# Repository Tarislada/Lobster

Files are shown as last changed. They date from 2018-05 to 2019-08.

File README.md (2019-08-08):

# Lobster

Lobster Bot Project

folked from Sunwhi Kimm's project

revised by Knowblesse

# Folders
## Apparatus
- 3D CAD data

## ArduinoCode
- Controller.ino
- Lobster.ino
- Sucrose Pump.ino

## MatlabCode
- Behavior & Spike analysis codes

## PythonCode
- Experimental Machine learning codes

## Schematic
- Schematics for Custom Arduino Shield

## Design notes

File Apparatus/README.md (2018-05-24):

# Lobster Unit Code

Lobster Bot 데이터 분석 코드

# Files
## functions
[**BehavDataParser**](#behavdataparser) : TDT Open Bridge 에서 추출한 행동 데이터 csv 파일을 불러온다.

[**createGaussianHitmap**](#creategaussianhitmap) : XY data로부터 hitmap을 그려냅니다.

[**drawmap**](#drawmap) : createGaussianHitmap 데이터를 그려주는 함수. (createGaussianHitmap 함수 내에서 dodraw를 true로 설정하면 필요 없음.)

[**firedLocationParser**](#firedlocationparser) : spike time 데이터가 있는 txt 파일을 읽어서 위치와 연결해준다.

[**getHeadDegree**](#getheaddegree) : 이전좌표와 이후 좌표를 기반으로 움직인 방향의 각도를 구합니다. (X+ 축이 0도, Y+축이 90도 입니다.)

[**locationParser**](#locationparser) : XYXY csv 파일을 읽어서 위치 값들을 뽑아 출력한다.(recoverLocData 포함)

[**recoverLocData**](#recoverlocdata) : tracking loss로 인한 데이터 손실 부분을 주변 데이터를 토대로 추측해서 재구성한다.

## Scripts
**AnalyticValueExtractor** : BehavDataParser를 돌린 후 돌리면 각 trial 별 Avoid(A) / Escape(E) / 1 min timeout(M) / Give up(G) / No Lick(N) 값을 출력한다.

### BehavDataParser
- input
	- **targetdir : string(path) :** csv 파일들이 있는 경로
- output
	- **ParsedData : {1,4} cell :** {[TRON Time, TROF Time], [[IRON, IROF]], [[LICK,LOFF]], [[ATTK, ATOF]]}
	- **Trials : [n, 2] array :** [TRON Time, TROF Time]
	- **IRs : [n, 2] array :** [IRON, IROF]
	- **Licks : [n,2] array :** [LICK,LOFF]
	- **Attacks : [n,2] array :** [ATTK, ATOF]

### createGaussianHitmap
- input
	- **xydata : [n, 2] array :** [xdata, ydata]
	- **distribution : double :** gaussian 분포를 만들기 위한 sigma 값.
	- **stride : int :** 처리 속도 향상을 위해서 넣은 숫자만큼 데이터를 건너뛰어 읽음. 1로 설정시 모든 데이터를 사용.
	- **axis_limit : [1, 4] array :** [xmin, xmax, ymin, ymax] hitmap 데이터의 x축의 범위, y축의 범위를 설정해줌.
	- **dodraw : boolean :** true로 설정시 hitmap 그래프를 그림. false로 설정시 나중에 따로 그려주어야 함.
- output
	- **map : [n, n] array :** hitmap data. surf 함수를 사용해서 그릴것.

### drawmap
- input
	- **map : [n, n] array :** hitmap data. createGaussianHitmap 함수에서 출력됨.
	- **axis_limit : [1, 4] array :** [xmin, xmax, ymin, ymax] hitmap 데이터의 x축의 범위, y축의 범위를 설정해줌.
	- **c_axis_limit : [1, 2] array :** colorbar를 그리기 위한 한계값. 
- output
	- **map : [n, n] array :** hitmap data. surf 함수를 사용해서 그릴것.

### firedLocationParser
- input
	- **result : [n, 6] array :** [시간, Red X, Red Y, Green X, Green Y, Head Direction] locationParser가 뱉어내는 result 파일. (실제로는 첫 Col 만 사용)
- output
	- **firedIndices : [n, 1] array :** locationParser의 result 파일을 기준으로 unit이 fire한 시간과 가장 가까운 indices

### getHeadDegree
- input
	- **x1 : double :** t 시간의 x좌표 
	- **y1 : double :** t 시간의 y좌표
	- **x2 : double :** t+1 시간의 x좌표
	- **y2 : double :** t+1 시간의 y좌표
- output
	- **head_degree : double :** 각도.

### locationParser
- input
	- **dodraw : boolean :** 결과값을 그래프로 그릴 지 말지를 결정한다.
- output
	- **result : [n, 6] array :** [시간, Red X, Red Y, Green X, Green Y, Head Direction] 
- warning
	- Col 2-5의 데이터는 open bridge 설정에 따라 Red와 Green이 바뀔 수 있으므로 주의할 것.

### recoverLocData
- input
	- **originalLocData : {2, 2} cell :** { Red X , Green X; Red Y, Green Y}
	- **X_RANGE : [1,2] array :** 정상적인 X 값의 범위. [xmin, xmax]
	- **Y_RANGE : [1,2] array :** 정상적인 Y 값의 범위. [ymin, ymax]
- output
	- **recoveredLocData : {2, 2} cell :** { Red X , Green X; Red Y, Green Y}
- warning
	- open bridge 설정에 따라서 정상적인 X, Y의 범위를 나타내는 X_Range, Y_Range 값을 바꿔줘야할 경우가 있음.

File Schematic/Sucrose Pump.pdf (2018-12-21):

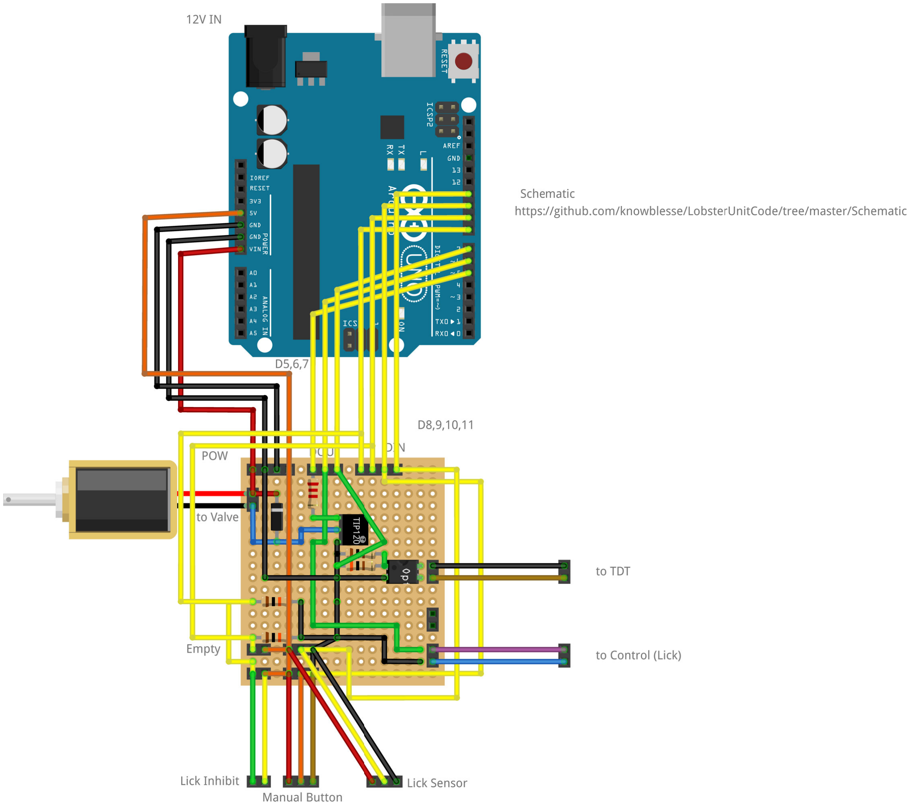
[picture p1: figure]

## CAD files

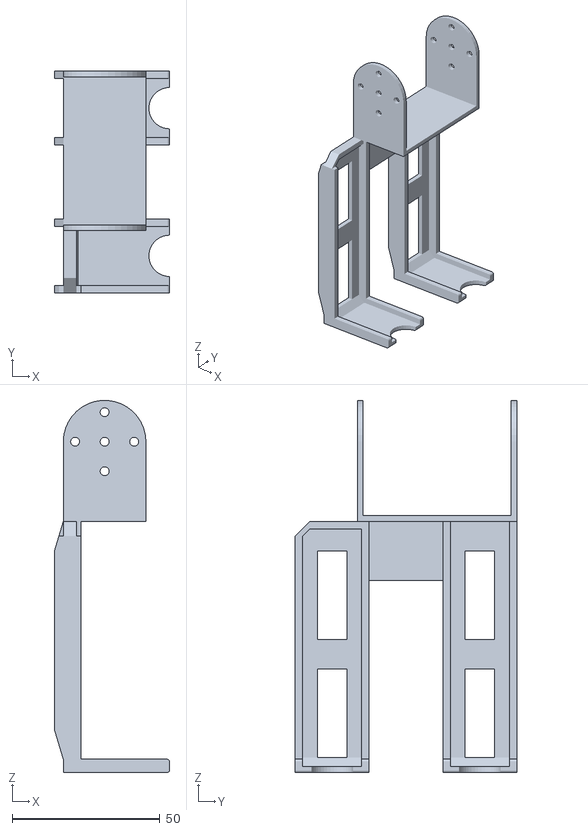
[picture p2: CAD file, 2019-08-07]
Apparatus/Box/servo_bracket_claw_left_v3-.STL
39.0 x 75.0 x 126.0

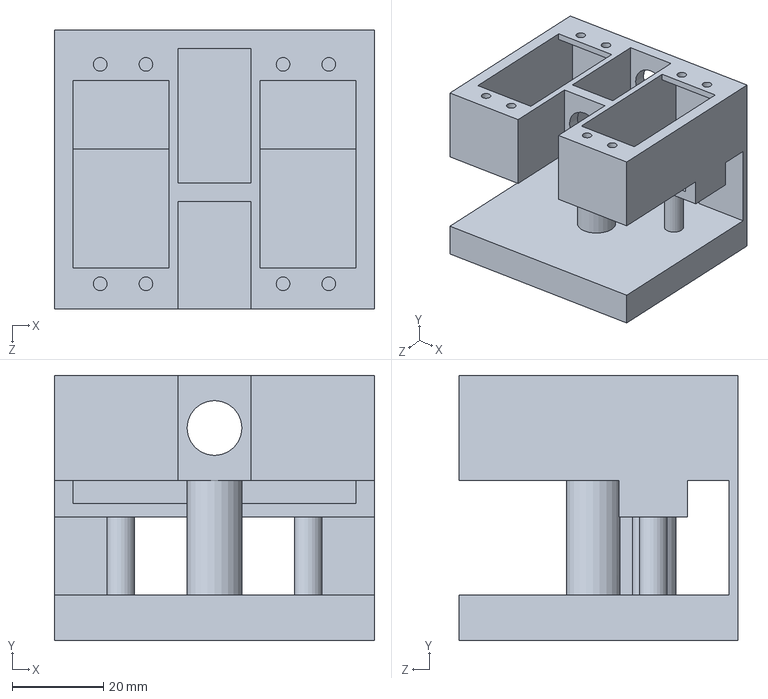
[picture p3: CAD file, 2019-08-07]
Apparatus/Box/LobsterServoBracket.SLDPRT
70.0 x 58.0 x 61.0 mm

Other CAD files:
Apparatus/Box/servo_bracket_claw_right_v3--.SLDPRT
Apparatus/Archived/servo_bracket_claw_right_v3--.SLDPRT
Apparatus/Archived/IR pcb shield_V2.ipt
Apparatus/Archived/LobsterServoBracket.STL
Apparatus/Archived/ass_lobbot.iam
Apparatus/Archived/ass_sucrose.iam
Apparatus/Archived/servo_bracket_claw_right_v3--.STL
Apparatus/Box/IR pcb shield_V2.ipt
Apparatus/Box/LobsterServoBracket.STL
Apparatus/Box/ass_lobbot.iam
Apparatus/Box/ass_sucrose.iam
Apparatus/Box/servo_bracket_claw_right_v3--.STL
Apparatus/Camera_Mount.ipt
Apparatus/DoorMotorDriveCase.ipt
Apparatus/Door_motor_bracket.ipt
Apparatus/LickModuleMount_Lobster.ipt
Apparatus/LickModuleMount_Training.ipt
Apparatus/LickSensorMount.ipt
Apparatus/LickSensorMount_H.ipt
Apparatus/MotorBracket.ipt
Apparatus/Top_Pulley.ipt
Apparatus/Top_Pulley_90.ipt
Apparatus/Visual/Board.ipt
Apparatus/Visual/FullApparatus.iam
Apparatus/Visual/IRLight.ipt
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

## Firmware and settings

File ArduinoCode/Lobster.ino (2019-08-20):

#include <Servo.h> 

const int PIN_ATTACK_IN_MANUAL = 8; 
const int PIN_ATTACK_IN = 9;
const int PIN_ATTACK_OUT = 10;

const int PIN_SERVO1 = 12; // Left 
const int PIN_SERVO2 = 11; // Right

const int PIN_SERVO_ON = 13;

Servo myservo1;
Servo myservo2;

void setup() 
{
  Serial.begin(9600);
  pinMode(PIN_ATTACK_IN, INPUT);
  pinMode(PIN_ATTACK_OUT, OUTPUT);
  pinMode(PIN_SERVO_ON, OUTPUT);

  digitalWrite(PIN_ATTACK_OUT,LOW);

  // initialize motor
  myservo1.attach(PIN_SERVO1);
  myservo2.attach(PIN_SERVO2);

  digitalWrite(PIN_SERVO_ON, HIGH);
  delay(50);
  myservo1.write(60);
  myservo2.write(145);
  delay(200);
  digitalWrite(PIN_SERVO_ON, LOW);
} 
 
void loop() 
{
  if(digitalRead(PIN_ATTACK_IN) == HIGH || digitalRead(PIN_ATTACK_IN_MANUAL) == HIGH) // Attack
  {
    // Send Attack Info to TDT
    digitalWrite(PIN_ATTACK_OUT,HIGH);

    // Perform Attack
    Serial.println("attack");
    attack();

    // Send Attack Info
    digitalWrite(PIN_ATTACK_OUT,LOW);
  }
}

void attack()
{
  digitalWrite(PIN_SERVO_ON, HIGH);
  delay(50);
  myservo1.write(100);               
  myservo2.write(105);
  delay(200);
  myservo1.write(60);  
  myservo2.write(145);
  delay(200);
  myservo1.write(100);               
  myservo2.write(105);
  delay(200);
  myservo1.write(60);
  myservo2.write(145);
  delay(200);
  digitalWrite(PIN_SERVO_ON, LOW);
}

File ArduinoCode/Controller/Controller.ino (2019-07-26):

/* 
  Created by Knowblesse, 2018-11-27
  Arduino Script for the Lobster Controller
*/


// Assign Pin Numbers
const int PIN_BLOCK_INPUT = 2;
const int PIN_BLOCK_OUTPUT = 3;

const int PIN_DOOR_INPUT = 6;
const int PIN_TRIAL_OUTPUT = 7;

const int PIN_LICK_INPUT = 10;

const int PIN_ATTK_OUTPUT = 5;
const int PIN_PUMP_OUTPUT = 4;

const int PIN_TONE_OUTPUT = 8;

const int PIN_MANUAL_SUC_INPUT = 11;
const int PIN_MANUAL_SUC_OUTPUT = 9;

const int PIN_CLEANUP = 12; // when on, pump and valve is on
const int PIN_PUMP_INPUT = 13;

// Event state boolean variables
bool isBlockSwitchOn = false;
bool isBlock = false;

bool isDoorClosed = true;
bool isTrial = false;

bool isAttackArmed = false;
bool isAttacked = false;

bool isBlockEverStarted = false;

// Time variable
unsigned long blockOnSetTime = 0;
unsigned long trialOnSetTime = 0;
unsigned long attackOnSetTime = 0;
unsigned long AT;

unsigned long maxLickTime = 6000; //max sucrose time 6000
unsigned long lickOffSetTime = 0;

// Etc.
int sa = 70; //six second attack probability
int trcount = 1;
int numLick = 0;
bool lickToggle = false;

void setup() 
{
  // Block Switch & LED
  pinMode(PIN_BLOCK_INPUT, INPUT);
  pinMode(PIN_BLOCK_OUTPUT, OUTPUT);
  digitalWrite(PIN_BLOCK_OUTPUT,LOW);

  // Trial Sensor & LED
  pinMode(PIN_DOOR_INPUT, INPUT); //because its a magnetic switch, 0 is on
  pinMode(PIN_TRIAL_OUTPUT, OUTPUT);
  digitalWrite(PIN_TRIAL_OUTPUT,LOW);

  pinMode(PIN_LICK_INPUT, INPUT);
  pinMode(PIN_ATTK_OUTPUT, OUTPUT);
  pinMode(PIN_PUMP_OUTPUT, OUTPUT);

  pinMode(PIN_MANUAL_SUC_INPUT, INPUT);
  pinMode(PIN_MANUAL_SUC_OUTPUT, OUTPUT);
  pinMode(PIN_CLEANUP, INPUT);

  // generate random seed
  randomSeed(analogRead(0));

  Serial.begin(9600);
  Serial.println("==========Current Protocol===========");
  Serial.print("Attack in 6sec : ");
  Serial.println(sa);
  Serial.print("Attack in 3sec : ");
  Serial.println(100-sa);
  Serial.println("=====================================");
}

void loop() 
{
  /*********************/
  /********Block********/
  /*********************/
  isBlockSwitchOn = digitalRead(PIN_BLOCK_INPUT);
  if(!isBlock) // not in block
  {
    if(isBlockSwitchOn == HIGH) // block digital switch on
    {
      digitalWrite(PIN_BLOCK_OUTPUT,HIGH);
      Serial.println("Block started");
      isBlockEverStarted = true;
      blockOnSetTime = millis();
      isBlock = true;
    }
  }
  else // in block
  {
    if(isBlockSwitchOn == LOW && blockOnSetTime + 500 < millis()/* + 500 for jittering*/) // block digital switch off
    {
      digitalWrite(PIN_BLOCK_OUTPUT,LOW);
      Serial.println("Block ended");
      if (isBlockEverStarted)
      {
        Serial.println("##########Experiment Finished##########");
        Serial.print("Number of Total Trials : ");
        Serial.println(trcount);
        Serial.print("Number of Total Licks : ");
        Serial.println(numLick);
        Serial.println("#######################################");
      }
      trcount = 1;
      isBlock = false;
    }
  }

  /*********************/
  /********Trial********/
  /*********************/
  isDoorClosed = digitalRead(PIN_DOOR_INPUT);
  if(!isDoorClosed) // Door opened = trial started
  {
    if(!isTrial) // Start Trial
    {
      trialOnSetTime = millis(); 
      digitalWrite(PIN_TRIAL_OUTPUT,HIGH);

      if(random(100) < sa)   //decide long or short attack onset time
        AT = 6000;
      else
        AT = 3000;
      
      // Print Trial Info
      Serial.print("trial : ");
      Serial.println(trcount);
      trcount = trcount+1;
      
      isTrial = true;
    }
    
    if(!isAttacked) // not attacked
    {
      if(!isAttackArmed) // not armed
      {
        if(digitalRead(PIN_LICK_INPUT)) // licked
        {
          isAttackArmed = true;
          attackOnSetTime = millis() + AT;
          lickOffSetTime = millis() + maxLickTime;

          Serial.print("Licked. Attack in ");
          Serial.print(AT);
          Serial.println("ms sec");
        }
      }
      else // armed
      {
        if(attackOnSetTime < millis()) // Attack Onset Time reached
        {
          digitalWrite(PIN_ATTK_OUTPUT,HIGH);
          delay(100);
          digitalWrite(PIN_ATTK_OUTPUT,LOW);
          Serial.println("##########Attacked!!##########");
          isAttacked = true;
        }
      }
    }
  }
  else // Door closed
  {
    if(isTrial) // finish trial
    {
      isTrial = false;
      isAttackArmed = false;
      isAttacked = false;

      digitalWrite(PIN_TRIAL_OUTPUT,LOW);
      
    }
  }

  // Manual Scrose and Pump
  if (digitalRead(PIN_CLEANUP) == HIGH){ // clean up mode
    digitalWrite(PIN_MANUAL_SUC_OUTPUT, HIGH);
    digitalWrite(PIN_PUMP_OUTPUT, HIGH);
  }
  else
  {
    digitalWrite(PIN_MANUAL_SUC_OUTPUT,digitalRead(PIN_MANUAL_SUC_INPUT));
    digitalWrite(PIN_PUMP_OUTPUT,digitalRead(PIN_PUMP_INPUT));
  }
  
  //Num Lick Count
  if(digitalRead(PIN_LICK_INPUT)==HIGH)
  {
    if(!lickToggle)
    {
      lickToggle = true;
      numLick++;
      if(numLick%10 == 0)
      {
        if(numLick%100 == 0)
        { 
          unsigned long timepassed = millis() - blockOnSetTime;
          Serial.print(long(timepassed / 1000 / 60));
          Serial.print(":");
          Serial.println((timepassed - long(timepassed / 1000 / 60) * 1000 * 60)/1000);
        }
        Serial.println(numLick);
      }


    }
  }
  else
  {
    if(lickToggle)
    {
      lickToggle = false;
    }
  }
}

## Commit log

2018-02-07 기존 작업 업로드
2018-02-25 샘플 데이터 첨부
    [Block-316_ATOF.csv, Block-316_ATTK.csv, Block-316_BLON.csv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]
2018-02-25 + gitignore 작성. + OpenBridge 행동 데이터 trial 별로 나눠주는 스크립트 완성
2018-02-26 * .gitignore 파일 편집 * BehavDataParser 함수화
2018-02-26 * BehavDataParser output 수정 및 출력값 수정 진행중 + 가능한 수치 다 뽑아내는 GetEverything 스크립트 작성 시작
2018-02-28 * BehavDataParser 단독 실행시 에러 수정. Lick, IR 모두 trial onset 시간을 기준으로 데이터를 로깅 - GetEverything : 이름 변경 -> ParameterSelector + ParameterSelector : 파라미터 설정을 위해 subject/experiment 상관없이 분석하는 코드 추가 + AnalyticVa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
2018-02-28 avoid escape 판별해주는 코드 작성중. TODO Attack과 마지막 IR Off 시간을 기준으로 avoid/escape 판별 필요
2018-02-28 주석 추가. trail 별로 분석해야하는 부분을 한데로 묶음. Inter Attack IROF Interval 구하는 공식 추가함.
2018-03-05 에러 수정
2018-03-08 string preallocation 파트에서 에러나는거 수정. 행동판별(G,M,A,E) 자동으로 해주는 부분 추가.
2018-03-08 Attack 과 IR 간의 간격 평균을 보기 위한 스크립트 추가
2018-03-23 Python EPM 분석코드 작성중
    [GR_EMP.csv]
2018-03-28 EPM SVM 돌리는 코드 완성. Feature 수 특정을 짓기 위해서 FeatureS.py 파일을 만듦.
2018-04-26 recoverLocData Y축 좌표도 받도록 수정
    주의. 기존에 사용하던 X축 Y축과 다름.
2018-04-26 선휘선배 코드 빠르게 변경
2018-05-17 위치 이동
    [Block-258_ATTK.csv, Block-258_BLON.csv, Block-258_IROF.csv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]
2018-05-22 ATOF 파일도 받아오도록 수정.
2018-05-23 주석 정리 및 doc 파일 완성
2018-05-24 README 파일 수정
2018-05-25 recoverLocData merge
    * X_RANGE, Y_RANGE 값을 받아서 돌아갈 수도 있고 값을 따로 넣지 않으면 선휘선배의 constant 값을 사용하도록 수정.
    * 필요 없는 공백 삭제
    * 코드 간결성 및 실행속도 향상.
2018-05-25 파일 합침
    [Block-258_ATTK.csv, Block-258_BLON.csv, Block-258_IROF.csv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]
2018-06-19 Align된 피겨 그리기 + pca 분석용 data 추출 스크립트
2018-06-19 모든 .mat 파일 이벤트 별로 합침
2018-06-19 A3_v2 주석처리 및 마무리
2018-06-19 A3_v3 주석처리 및 마무리
2018-06-19 MakeBigArray 이름 변경 및 주석처리
2018-06-19 주석처리
2018-06-20 git ignore 업데이트
2018-06-27 새로운 XYXY 형식 뽑아내는 코드
2018-07-03 //WIP trial 로 나눠서 분석하는 코드
2018-07-04 Trial 별로 나눠서 분석하는 코드 완성
2018-07-12 주석 수정
2018-07-12 두 번째로 돌리는 코드는 문제가 생기는 오류 수정
    struct 형의 Z 값을 만드는데 문제는 workspace에 Z 값이 존재하면 indexing이 불가능하다는 오류가 나왔었음.
2018-07-12 Edge 사이즈 전부 통일
    이벤트 별로 달랐던 시간축을 전부 -4초에서 +4초까지 0.1초 간격으로 변경
2018-07-13 edge 길이 통일한 것 반영
2018-08-03 message output update
    - 파일 불러올 때 .mat이 아니라 .txt 형식만 불러오도록 변경(원래 .txt 만 사용함)
    - 사용한 .txt 파일이 있던 위치에 각 유닛별 .mat 파일을 형성
    - 몇개의 유닛 데이터가 만들어졌는지 출력
2018-08-06 targetdir 값 자동 입력
    선택한 뉴런의 mat 파일 위치에서 EVENT 폴더를 자동으로 선택하도록 변경.
2018-08-06 어짜피 쓰지도 않는 BLOCK 정보 빼버림
2018-08-13 AlignEvent Batch Complete
    [IROF_new.xlsx]
2018-08-28 LDA added
    [EVENT.csv]
2018-11-22 Arduino files uploaded
2018-11-22 Arduino Code Added
2018-11-22 editting arduino code
2018-11-26 Controller Code Finished
    issues to solve : Block ON/OFF
    TROF initialize seq bug
    [Controller.ino]
2018-11-27 trof error resolved, message added
    [Controller.ino]
2018-11-27 Sucrose Pump.ino WIP
2018-11-30 Stupid time related bug fixed + manual sucrose button added
    [Controller.ino]
2018-12-03 Manual button for Suc. pump from the Controller
2018-12-06 Pin Config changed
2018-12-06 Sucrose Pump Schematics uploaded
    [Sucrose Pump.fzz]
2018-12-10 Schematics updated
    [Sucrose Pump.fzz]
2018-12-21 Pin Config. changed
    [Sucrose Pump.fzz]
2018-12-21 D13 as Lick LED, Inhibit part changed
2019-05-22 Pump On and Power On LED added
2019-07-19 Valve Inhibit function deleted
2019-07-19 manual pump button added
2019-07-19 numLick Serial print
2019-07-21 WIP - Pump Error temporary fix
    [Controller.ino]
2019-07-24 Print time of every 100 lick
2019-07-24 Attk Mode bug fixed
    [Controller.ino]
2019-08-05 Manual Lick Button deleted
    Physically removed the button (white one).
    Somehow digital HIGH was still going into the pin 10, so I deleted that part of the code.
2019-08-07 Initial Commit for 3d apparatus files
    [IR pcb shield_V2.ipt, LickSensorMount.ipt, LobsterServoBracket.SLDPRT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]
2019-08-08 Apparatus folder reconfigured
    [IR pcb shield_V2.ipt, LickModuleMount_Lobster.ipt, LickModuleMount_Training.ipt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]
2019-08-08 Lobsterbot bug fixed
    - no jittering of the left arm
    - HF noise removed
    - arms are
    [Controller.ino, Lobster.ino]
2019-08-09 Tube thickness increased
    [WaterDrainWell.ipt]
2019-08-09 Motor bug fixed
    Removed "Servo.detach()"
    instead, TIP120 Darlington T was used (Pin13);
    [Lobster.ino]
2019-08-09 Manual Attack button added, Attack motion changed
2019-08-13 Parts added
    [LickModuleMount_Lobster.ipt, LickSensorMount.ipt, LickSensorMount_H.ipt]
2019-08-13 Sensor and Lick hole realigned
    [LickSensorMount.ipt, LickSensorMount_H.ipt]
2019-08-15 WaterDrainWell is widen
    [WaterDrainWell.ipt]
2019-08-15 Wheel added (automatic door)
    [LickSensorMount.ipt, LickSensorMount_H.ipt, Wheel.ipt]
2019-08-20 Wheel size reduced
    [LickModuleMount_Training.ipt, WaterDrainWell.ipt, Wheel.ipt]
2019-08-20 Smooth edge
    [WaterDrainWellMount.ipt]
2019-09-27 Apparatus Visual Art added
    [Board.ipt, FullApparatus.0001.iam, FullApparatus.iam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]
2019-10-09 Apparatus renewal parts added
    [Camera_Mount.ipt, Door_motor_bracket.ipt, Top_Pulley.ipt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]
2019-10-23 Pin num changed + shorter delay
2019-10-24 Continuous manual lick button bug fixed
    [Controller.ino]
2019-10-25 pin number changed
2019-10-25 Manual Attack message bug fixed
    [Controller.ino]
2019-10-25 lick count error fixed
    [Controller.ino]
2019-10-28 DoorMotorDriveCase added
    [DoorMotorDriveCase.ipt]
2019-10-31 sucrose pump dead code erased
2019-10-31 Version 2.1
    Message output changed
    minor error fixed
    [Controller.ino]
2019-11-01 arduino controller code added
